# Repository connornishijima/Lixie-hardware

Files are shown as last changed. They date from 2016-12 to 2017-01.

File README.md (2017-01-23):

Lixie

#Hardware repository for Lixie edge-lit displays!

This repository contains all of the files necessary to build your own Lixie displays. This includes the EAGLE files for the boards, the .eps layouts for the lasercut parts, and CAD files if you want to design accessories. Documentation is also included.

----------
# Contents
- [Bill of Materials](#bill-of-materials)
- [Contributing](#contributing)
- [License and credits](#license-and-credits)

----------
# Bill of Materials

### Lasercut
Part | Material | Quantity
---- | -------- | -------:
0-9 Digits | 1.5mm clear acrylic | 1 set
Top Cover | 1.5mm black acrylic | 1
Top Bracket | 5.2mm birch | 1
Bottom Bracket | 5.2mm birch | 1

### PCB
Part | Description | Quantity
---- | ----------- | -------:
Lixie PCB | The brains of the operation | 1
WS2812B | Addressable LEDs | 20
Capacitor | 1000uF / 6.3V | 1

### Hardware
Part | Description | Quantity
---- | ----------- | -------:
M2.5 Bolt | 25mm length | 4
M2.5 Nut | | 4

A more detailed bill of materials is located in the "Documentation" folder.

----------
# Contributing
Any advice or pull requests are welcome. :)

----------
# License and Credits
**Developed by Connor Nishijima (2016)**

**Released under the [GPLv3 license](http://www.gnu.org/licenses/gpl-3.0.en.html).**

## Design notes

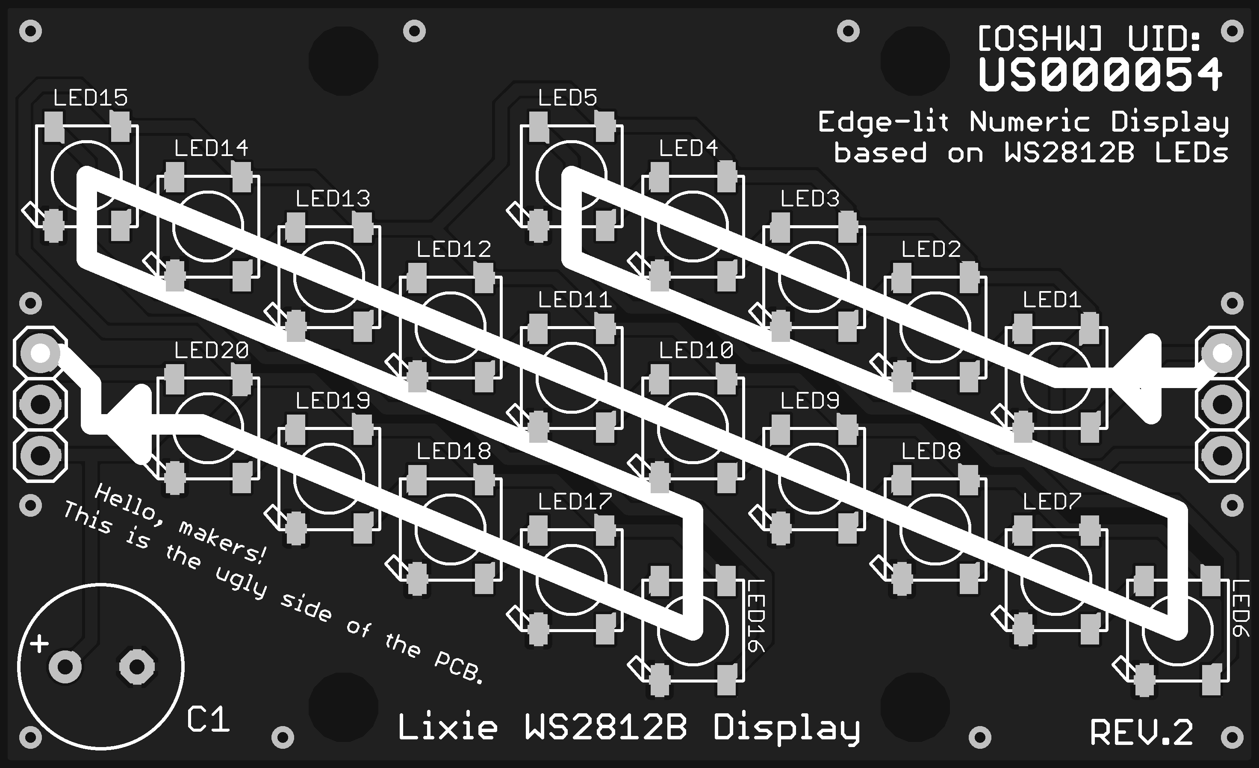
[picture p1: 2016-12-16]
DOCUMENTATION/pcb_top.png

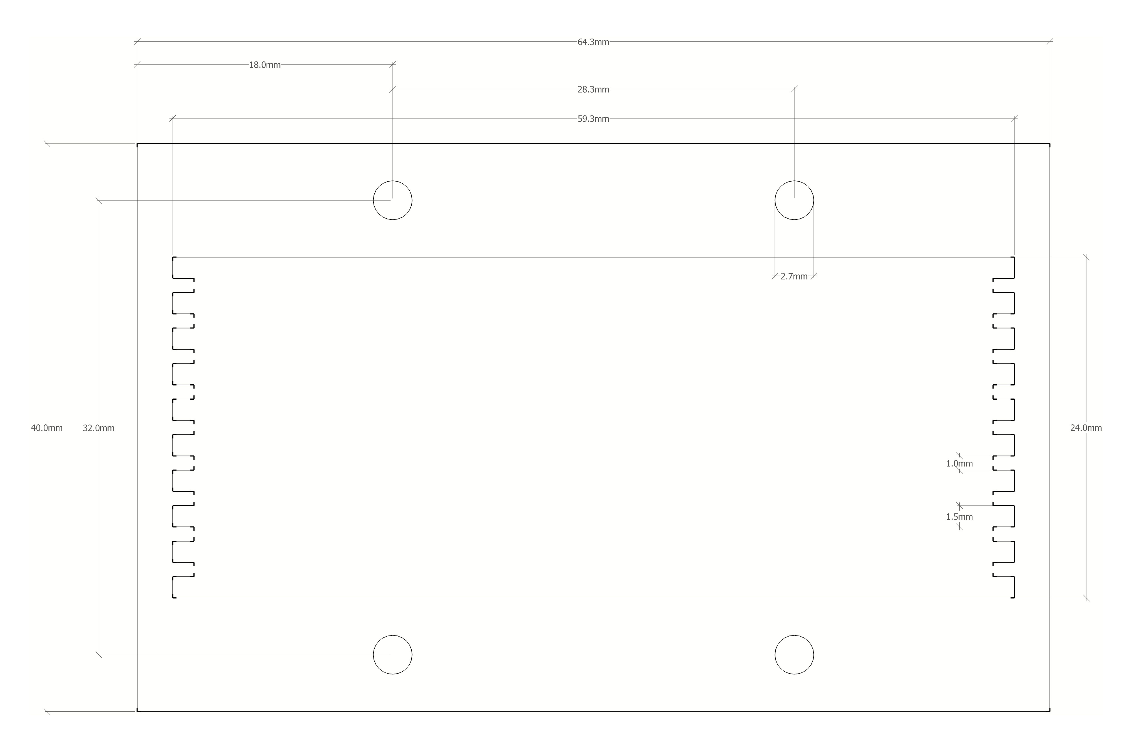
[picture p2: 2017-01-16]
DOCUMENTATION/Dimensions/lixie_dimensions_footprint.jpg

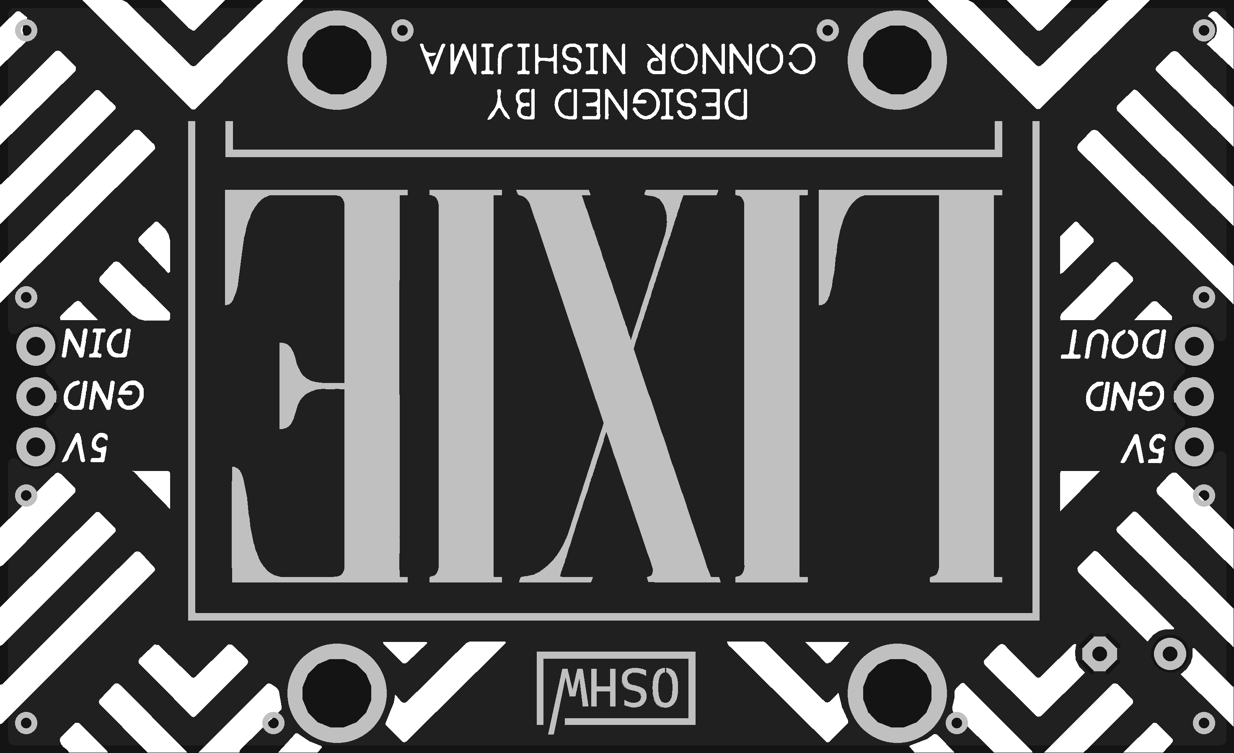
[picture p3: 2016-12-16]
DOCUMENTATION/pcb_bottom.png

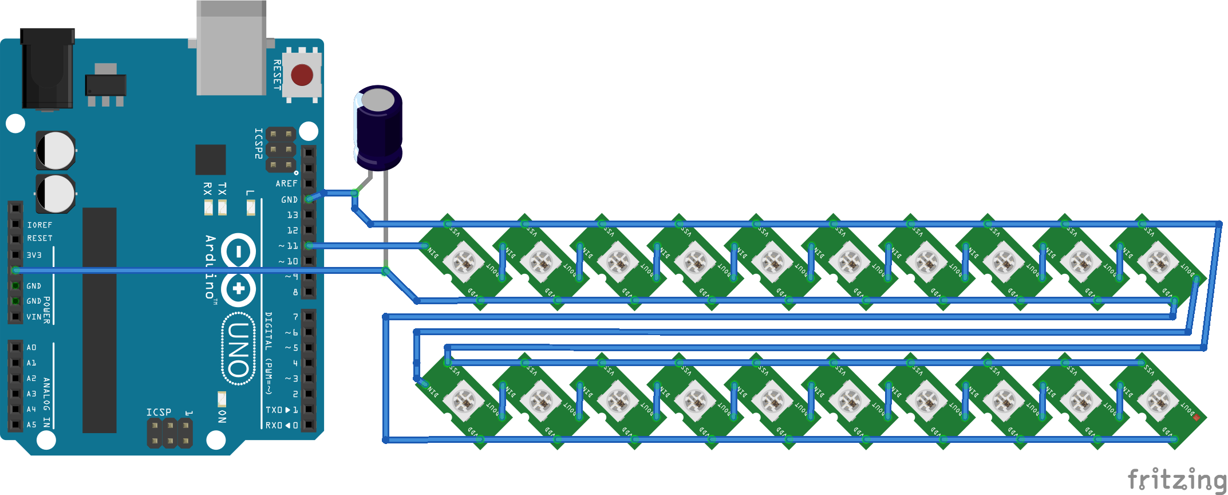
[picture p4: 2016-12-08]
FRITZING/LIXIE.png

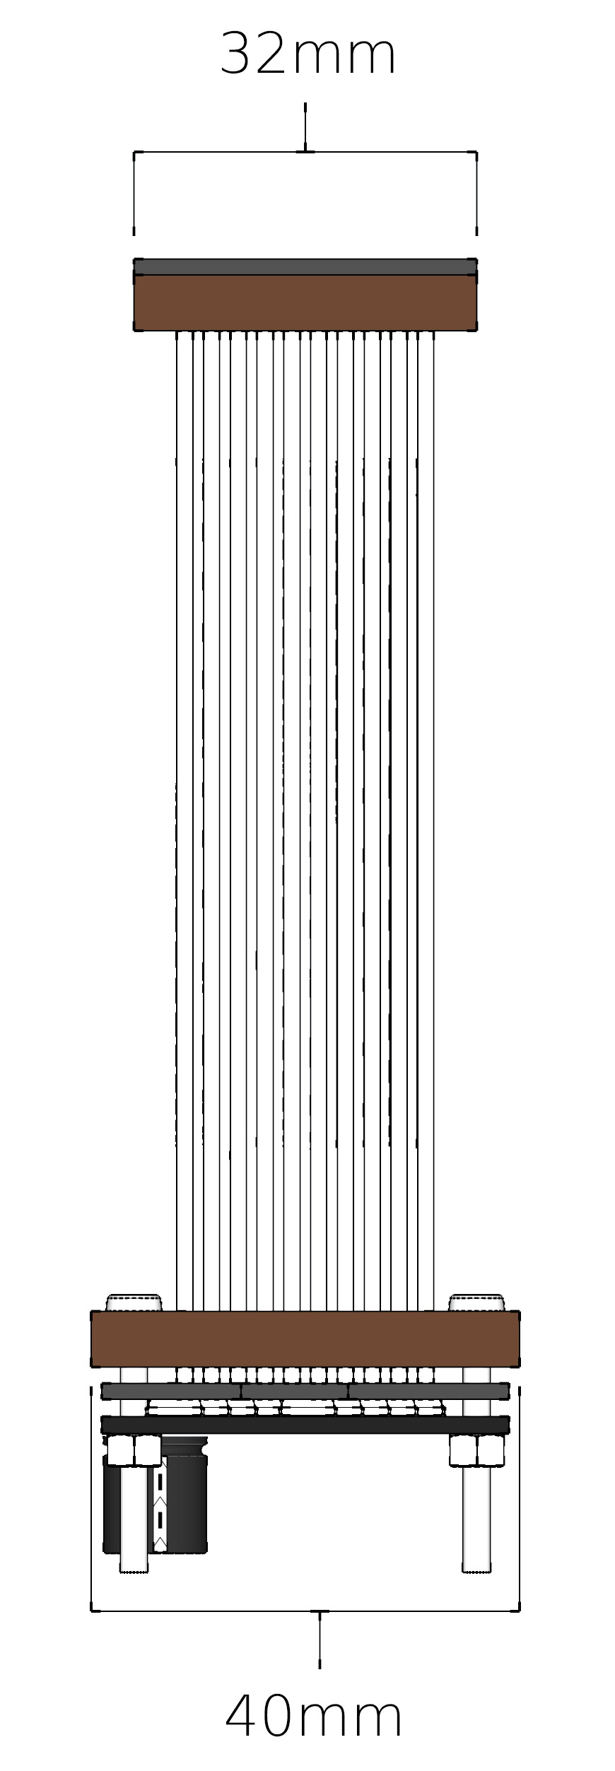
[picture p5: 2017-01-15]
DOCUMENTATION/Dimensions/lixie_dimensions_right.jpg

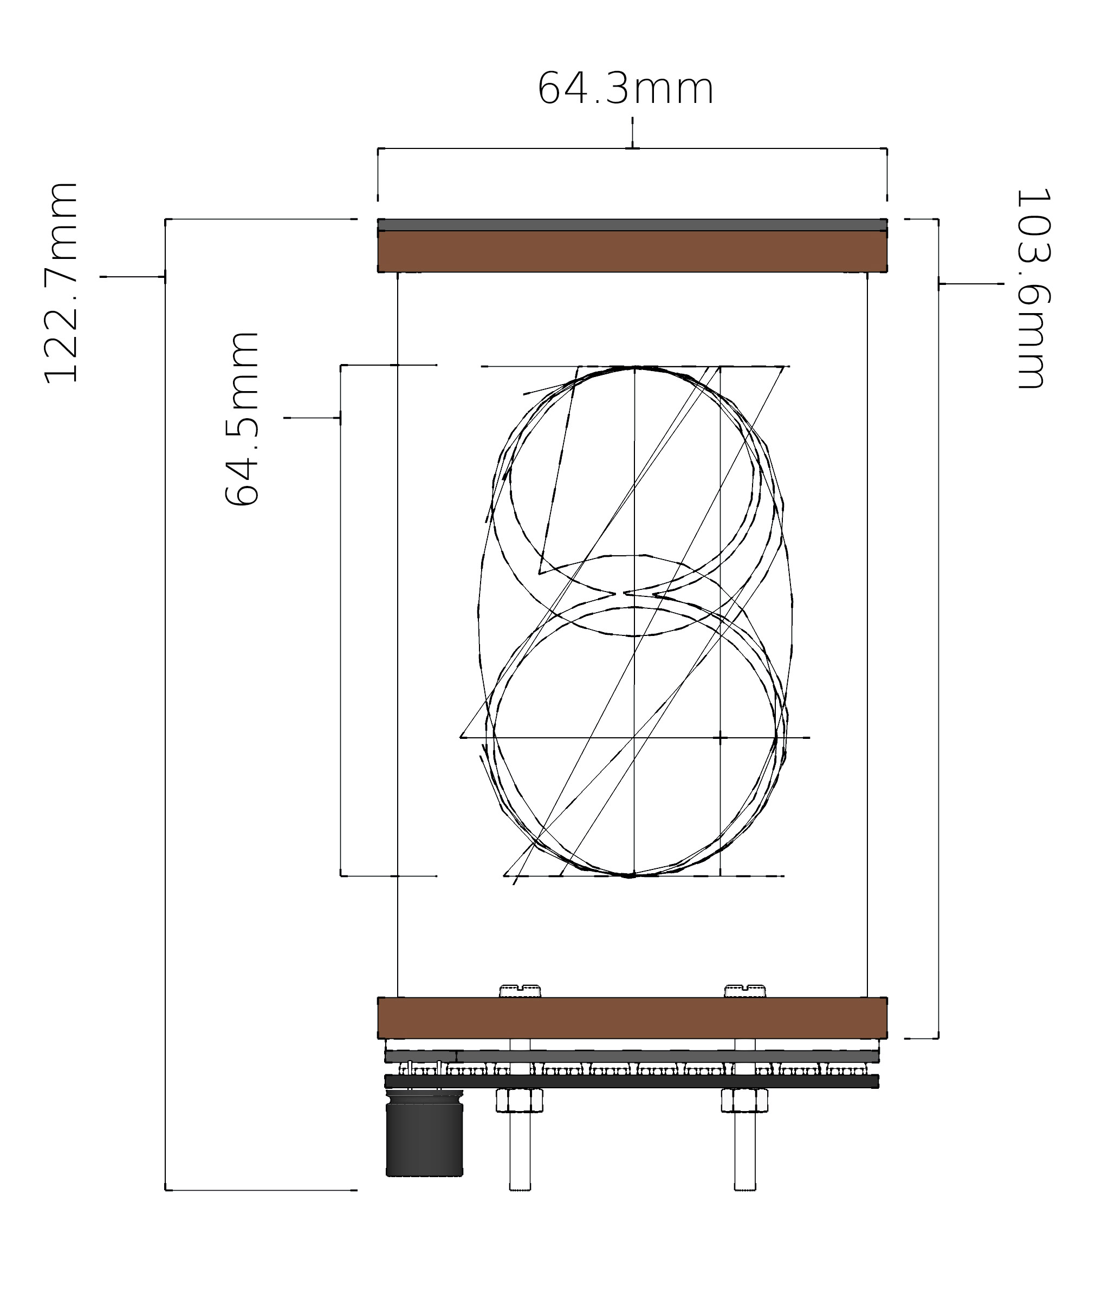
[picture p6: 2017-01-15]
DOCUMENTATION/Dimensions/lixie_dimensions_front.jpg

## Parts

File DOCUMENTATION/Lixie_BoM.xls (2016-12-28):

Lixie Display – Bill Of Materials
Last updated: 12/28/2016
Name | Quantity | Value | Package | Designator | Vendor | Part Number | Lead Time | Link
WS2812B | 20 | 5V RGB LED | 5050 SMD | LED1-20 | AliExpress |  | 2 Weeks | https://www.aliexpress.com/item/1000pcs-WS2812B-4pin-5050-SMD-RGB-LED-with-built-in-WS2811-IC-inside/1202431005.html
Capacitor | 1 | CAP ALUM 1000UF 20% 6.3V RADIAL | 5mm Pitch, 8mm Dia. | C1 | DigiKey | 493-5895-1-ND | 3 Days | http://www.digikey.com/scripts/DkSearch/dksus.dll?Detail&itemSeq=215117627&uq=636184869557072807
PCB | 1 | 2-Layer FR4 HASL |  |  | DirtyPCBs |  | 7 Days | http://dirtypcbs.com/store/pcbs
Bolt | 4 | 25mm M2.5 Bolt |  |  | AliExpress |  | 3 Weeks | https://www.aliexpress.com/item/40pcs-M2-5-25mm-M2-5-25mm-304-Stainless-Steel-Round-Head-Bolt-Cross-Recessed-Screw/32698761062.html
Nut | 4 | M2.5 Nut |  |  | Aliexpress |  | 3 Weeks | https://www.aliexpress.com/item/40pcs-M2-5-25mm-M2-5-25mm-304-Stainless-Steel-Round-Head-Bolt-Cross-Recessed-Screw/32698761062.html
Birch | 1 | 5.2mm | P3 |  | Ponoko |  | 2 Weeks | http://www.ponoko.com/make-and-sell/show-material/84-veneer-core-birch
Black Acrylic | 1 | 1.5mm | P3 |  | Ponoko |  | 2 Weeks | http://www.ponoko.com/make-and-sell/show-material/79-acrylic-black
Clear Acrylic | 1 | 1.5mm | P3 |  | Ponoko |  | 2 Weeks | http://www.ponoko.com/make-and-sell/show-material/72-acrylic-clear

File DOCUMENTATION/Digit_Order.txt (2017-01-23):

From front to back: 6, 5, 7, 4, 8, 3, 9, 2, 0, 1

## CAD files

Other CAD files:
CAD/LIXIE_REV2.skp

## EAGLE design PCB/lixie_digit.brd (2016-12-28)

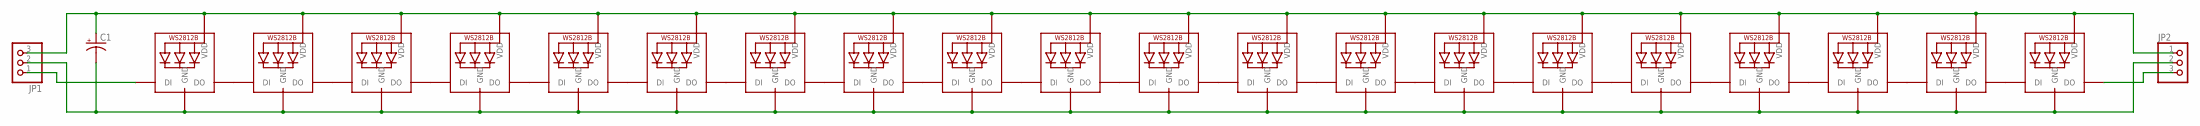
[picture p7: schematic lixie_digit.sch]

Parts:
C1: CPOL-USE3.5-8; E3,5-8
JP1, JP2: PINHD-1X3; 1X03
LED1, LED2, LED3, LED4, LED5, LED6, LED7, LED8, LED9, LED10, LED11, LED12, LED13, LED14, LED15, LED16, LED17, LED18, LED19, LED20: WS2812B5050; WS2812B

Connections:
GND: C1.-, JP1.2, JP2.2, LED1.3-GND (GND), LED2.3-GND (GND), LED3.3-GND (GND), LED4.3-GND (GND), LED5.3-GND (GND), LED6.3-GND (GND), LED7.3-GND (GND), LED8.3-GND (GND), LED9.3-GND (GND), LED10.3-GND (GND), LED11.3-GND (GND), LED12.3-GND (GND), LED13.3-GND (GND), LED14.3-GND (GND), LED15.3-GND (GND), LED16.3-GND (GND), LED17.3-GND (GND), LED18.3-GND (GND), LED19.3-GND (GND), LED20.3-GND (GND)
unnamed: LED1.2-DOUT (DO), LED2.4-DIN (DI)
unnamed: LED2.2-DOUT (DO), LED3.4-DIN (DI)
unnamed: LED3.2-DOUT (DO), LED4.4-DIN (DI)
unnamed: LED4.2-DOUT (DO), LED5.4-DIN (DI)
unnamed: LED5.2-DOUT (DO), LED6.4-DIN (DI)
unnamed: LED6.2-DOUT (DO), LED7.4-DIN (DI)
unnamed: LED7.2-DOUT (DO), LED8.4-DIN (DI)
unnamed: LED8.2-DOUT (DO), LED9.4-DIN (DI)
unnamed: LED9.2-DOUT (DO), LED10.4-DIN (DI)
unnamed: LED10.2-DOUT (DO), LED11.4-DIN (DI)
unnamed: LED11.2-DOUT (DO), LED12.4-DIN (DI)
unnamed: LED12.2-DOUT (DO), LED13.4-DIN (DI)
unnamed: LED13.2-DOUT (DO), LED14.4-DIN (DI)
unnamed: LED14.2-DOUT (DO), LED15.4-DIN (DI)
unnamed: LED15.2-DOUT (DO), LED16.4-DIN (DI)
unnamed: LED16.2-DOUT (DO), LED17.4-DIN (DI)
unnamed: LED17.2-DOUT (DO), LED18.4-DIN (DI)
unnamed: LED18.2-DOUT (DO), LED19.4-DIN (DI)
unnamed: LED19.2-DOUT (DO), LED20.4-DIN (DI)
unnamed: C1.+, JP1.3, JP2.1, LED1.1-VDD (VDD), LED2.1-VDD (VDD), LED3.1-VDD (VDD), LED4.1-VDD (VDD), LED5.1-VDD (VDD), LED6.1-VDD (VDD), LED7.1-VDD (VDD), LED8.1-VDD (VDD), LED9.1-VDD (VDD), LED10.1-VDD (VDD), LED11.1-VDD (VDD), LED12.1-VDD (VDD), LED13.1-VDD (VDD), LED14.1-VDD (VDD), LED15.1-VDD (VDD), LED16.1-VDD (VDD), LED17.1-VDD (VDD), LED18.1-VDD (VDD), LED19.1-VDD (VDD), LED20.1-VDD (VDD)
unnamed: JP1.1, LED1.4-DIN (DI)
unnamed: JP2.3, LED20.2-DOUT (DO)

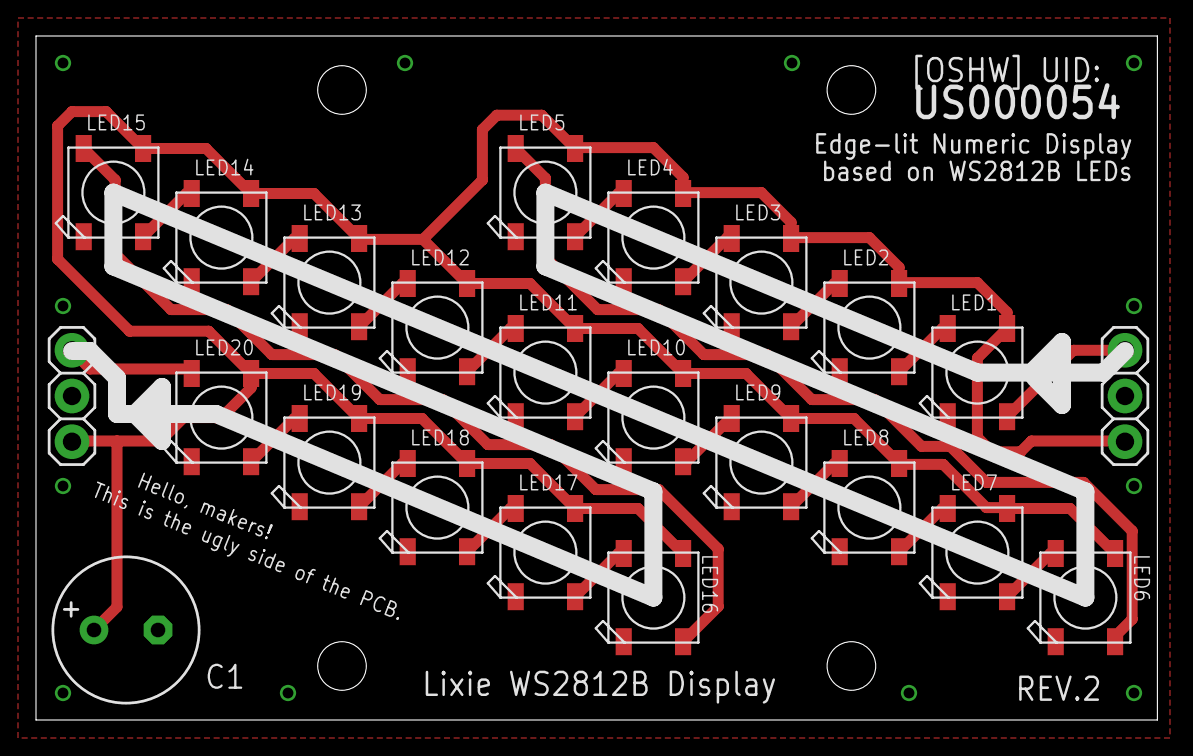
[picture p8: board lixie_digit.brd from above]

Board: 2 copper layers, 62.3 x 38.0 mm, 23 parts (0 on the bottom side), 23 nets.

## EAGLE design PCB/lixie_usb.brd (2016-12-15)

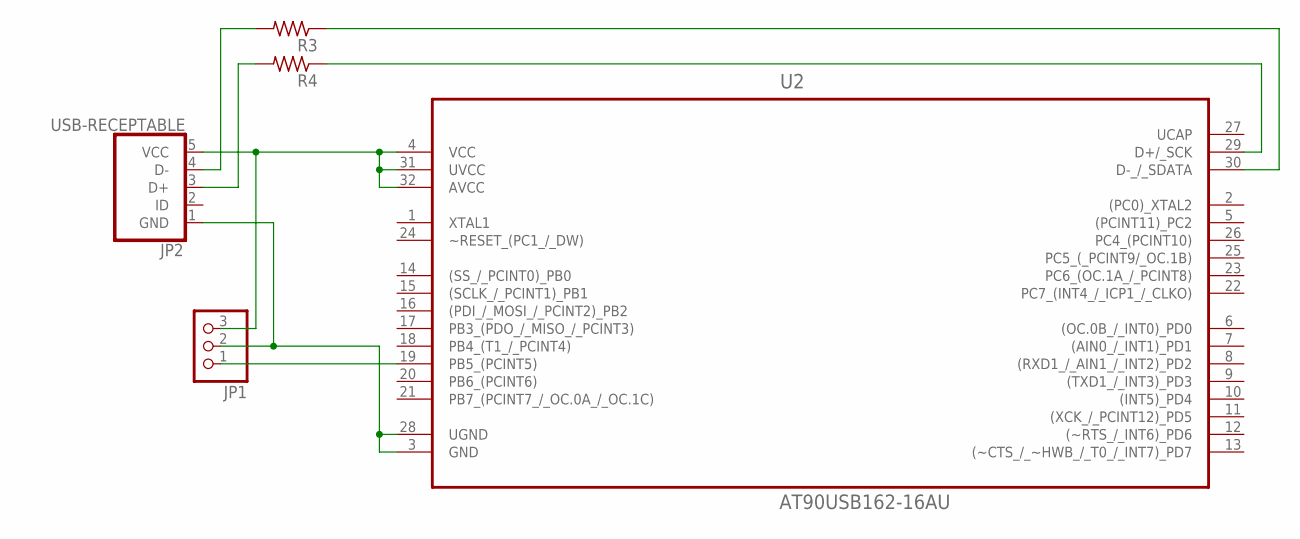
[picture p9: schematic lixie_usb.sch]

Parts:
JP1: PINHD-1X3; 1X03
JP2: USB-RECEPTABLE; FCI-10103594-0001LF
R3, R4: R-US_R0805; R0805
U2: AT90USB162-16AU; QFP80P900X900X120-32N

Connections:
GND: JP1.2, JP2.1 (GND), U2.3 (GND), U2.28 (UGND)
unnamed: R3.1, U2.30 (D-_/_SDATA)
unnamed: JP2.4 (D-), R3.2
unnamed: JP2.3 (D+), R4.2
unnamed: R4.1, U2.29 (D+/_SCK)
unnamed: JP1.3, JP2.5 (VCC), U2.4 (VCC), U2.31 (UVCC), U2.32 (AVCC)
unnamed: JP1.1, U2.19 (PB5_(PCINT5))

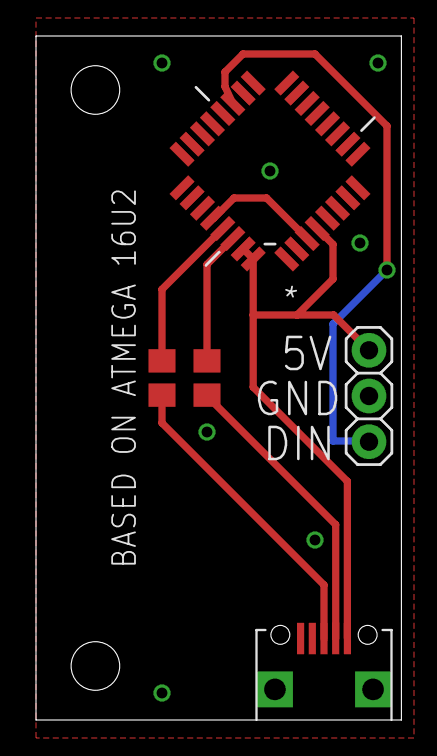
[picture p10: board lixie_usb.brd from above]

Board: 2 copper layers, 20.3 x 38.0 mm, 5 parts (0 on the bottom side), 7 nets.

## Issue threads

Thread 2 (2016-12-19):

Add an aux power connector

dmadison, 2016-12-19:
It might be a good idea to add an auxiliary power connector to the back of the board (or at least the pads for one), to add supplementary power for larger installations.

Closed 2017-10-09.

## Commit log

2016-12-02 Added Open Source Files
    [lixie_digit.brd, lixie_digit.sch]
2016-12-08 Rewrites begin!
    [LIXIE.fzz]
2016-12-08 Separated Lixie into software and hardware repository!
    [LIXIE.fzz, lixie_digit.brd, lixie_digit.sch]
2016-12-10 Added Revision 2 PCB!
    [lixie_digit.brd]
2016-12-11 Added Sketchup CAD File!
    [LIXIE_REV2.skp]
2016-12-12 Added OSHWA Cerified PCB!
    [LIXIE_REV2.skp, lixie_digit.brd, lixie_digit.sch]
2016-12-15 Added USB daughter board!
    [lixie_usb.brd, lixie_usb.sch]
2016-12-16 Updated PCB DOUT side to fix ground plane issue.
    [lixie_digit.brd]
2016-12-16 Updated all PCB/CAD with groundplane fix!
    [lixie_digit.brd]
2016-12-28 Added bill of materials!
    [Lixie_BoM.xls, lixie_digit.brd]
2017-01-16 Added footprint dimensions and SVG!
2017-01-18 Moved bill of materials to documentation
    [Lixie_BoM.xls]
2017-01-18 Moved PCB images to documentation
2017-01-18 Renamed PCB images
2017-01-18 Added Bill of Materials to README
    Just as a quick reference!
2017-01-23 Added full CAD assembly in STEP format
